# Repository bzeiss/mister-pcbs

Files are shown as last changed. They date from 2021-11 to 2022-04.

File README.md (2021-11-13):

# mister-pcbs

This site contains some stuff I have built for the excellent Mister project. You can more about the Mister project here: https://github.com/MiSTer-devel/Main_MiSTer/wiki

I tinker with electronics, release stuff when I feel like it and I make it public when it's maybe not perfect. I'm not an electronics expert, so I may not always know what I'm doing. I learn the necessary electronics as I use it. Use at your own risk.

Be smart. Don't just trust the stuff I offer for download here. Take a look at the schematic and the PCB design beforehand. 

Feedback is always very welcome :smile: Feel free to ask question in the [discussions](https://github.com/bzeiss/mister-pcbs/discussions).

***

The main content of this site (descriptions, documentations) can be found **[in the Wiki](https://github.com/bzeiss/mister-pcbs/wiki)**.

Entrance (https://github.com/bzeiss/mister-pcbs/wiki)

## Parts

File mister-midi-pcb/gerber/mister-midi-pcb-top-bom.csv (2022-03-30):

Comment | Designator | Footprint | LCSC Part Number
100nF | C1 | Capacitor_SMD:C_0805_2012Metric_Pad1.18x1.45mm_HandSolder | C49678
10uF | C2,C3 | Capacitor_Tantalum_SMD:CP_EIA-3216-18_Kemet-A_Pad1.58x1.35mm_HandSolder | C7171
1N4148 | D1 | Diode_SMD:D_SOD-323_HandSoldering | C2128
Green LED | D2 | LED_SMD:LED_0805_2012Metric_Pad1.15x1.40mm_HandSolder | C2297
Blue LED | D3 | LED_SMD:LED_0805_2012Metric_Pad1.15x1.40mm_HandSolder | C2293
Yellow LED | D4 | LED_SMD:LED_0805_2012Metric_Pad1.15x1.40mm_HandSolder | C2296
Ferrite_Bead | FB1,FB2,FB3,FB4,FB5,FB6 | Capacitor_SMD:C_0805_2012Metric_Pad1.18x1.45mm_HandSolder | C85835
220 | R1 | Resistor_SMD:R_0805_2012Metric_Pad1.20x1.40mm_HandSolder | C17557
470 | R2 | Resistor_SMD:R_0805_2012Metric_Pad1.20x1.40mm_HandSolder | C17710
2k | R3,R8,R9 | Resistor_SMD:R_0805_2012Metric_Pad1.20x1.40mm_HandSolder | C17604
33 | R4,R5 | Resistor_SMD:R_0805_2012Metric_Pad1.20x1.40mm_HandSolder | C17634
10 | R6,R7 | Resistor_SMD:R_0805_2012Metric_Pad1.20x1.40mm_HandSolder | C17415
H11L1 | U1 | Package_DIP:SMDIP-6_W9.53mm_Clearance8mm | C899473
74HC14 | U2 | Package_SO:SO-14_3.9x8.65mm_P1.27mm | C5605
LM1117-3.3 | U3 | Package_TO_SOT_SMD:SOT-223-3_TabPin2 | C126027

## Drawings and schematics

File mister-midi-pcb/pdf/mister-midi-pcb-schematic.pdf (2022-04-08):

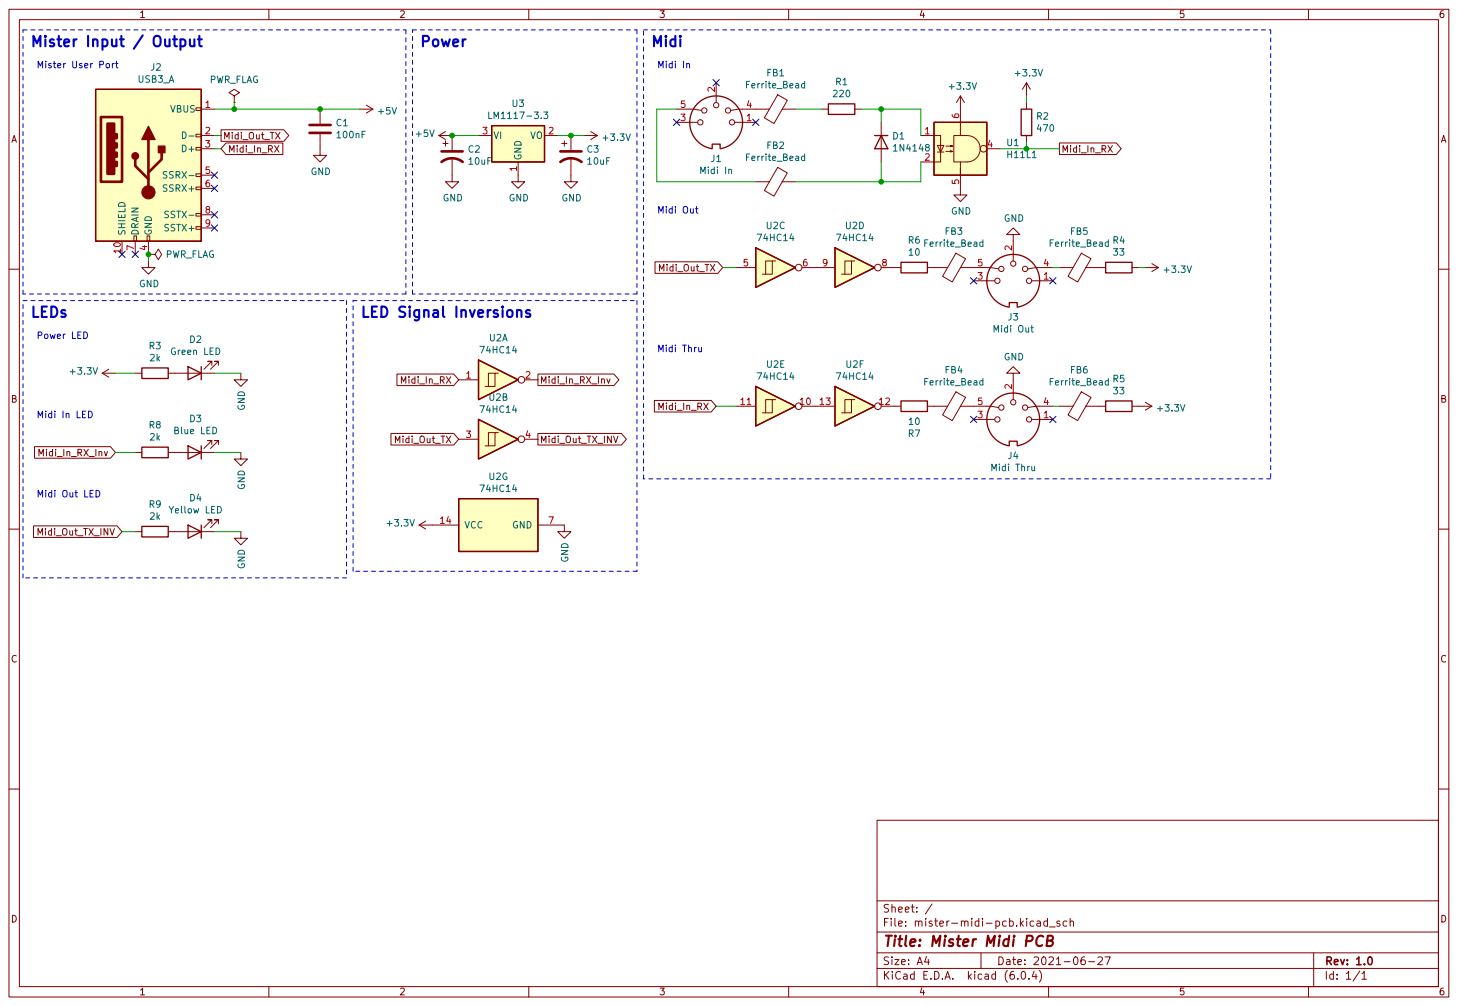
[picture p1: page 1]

Power LED Mister Input / Output

5 6 U1H11L1 Midi_In_RX Midi_Out_TX Midi_In_RX_Inv Midi_Out_TX Midi_In_RX Midi_In_RX Midi_In_RX_Inv Midi_Out_TX Midi_Out_TX_INV Midi_In_RX Midi_Out_TX_INV Midi Thru Midi Out Midi Midi In Midi Out LED Midi In LED Power

File: mister-midi-pcb.kicad_sch Sheet: /
Id: 1/1 Title: Mister Midi PCB

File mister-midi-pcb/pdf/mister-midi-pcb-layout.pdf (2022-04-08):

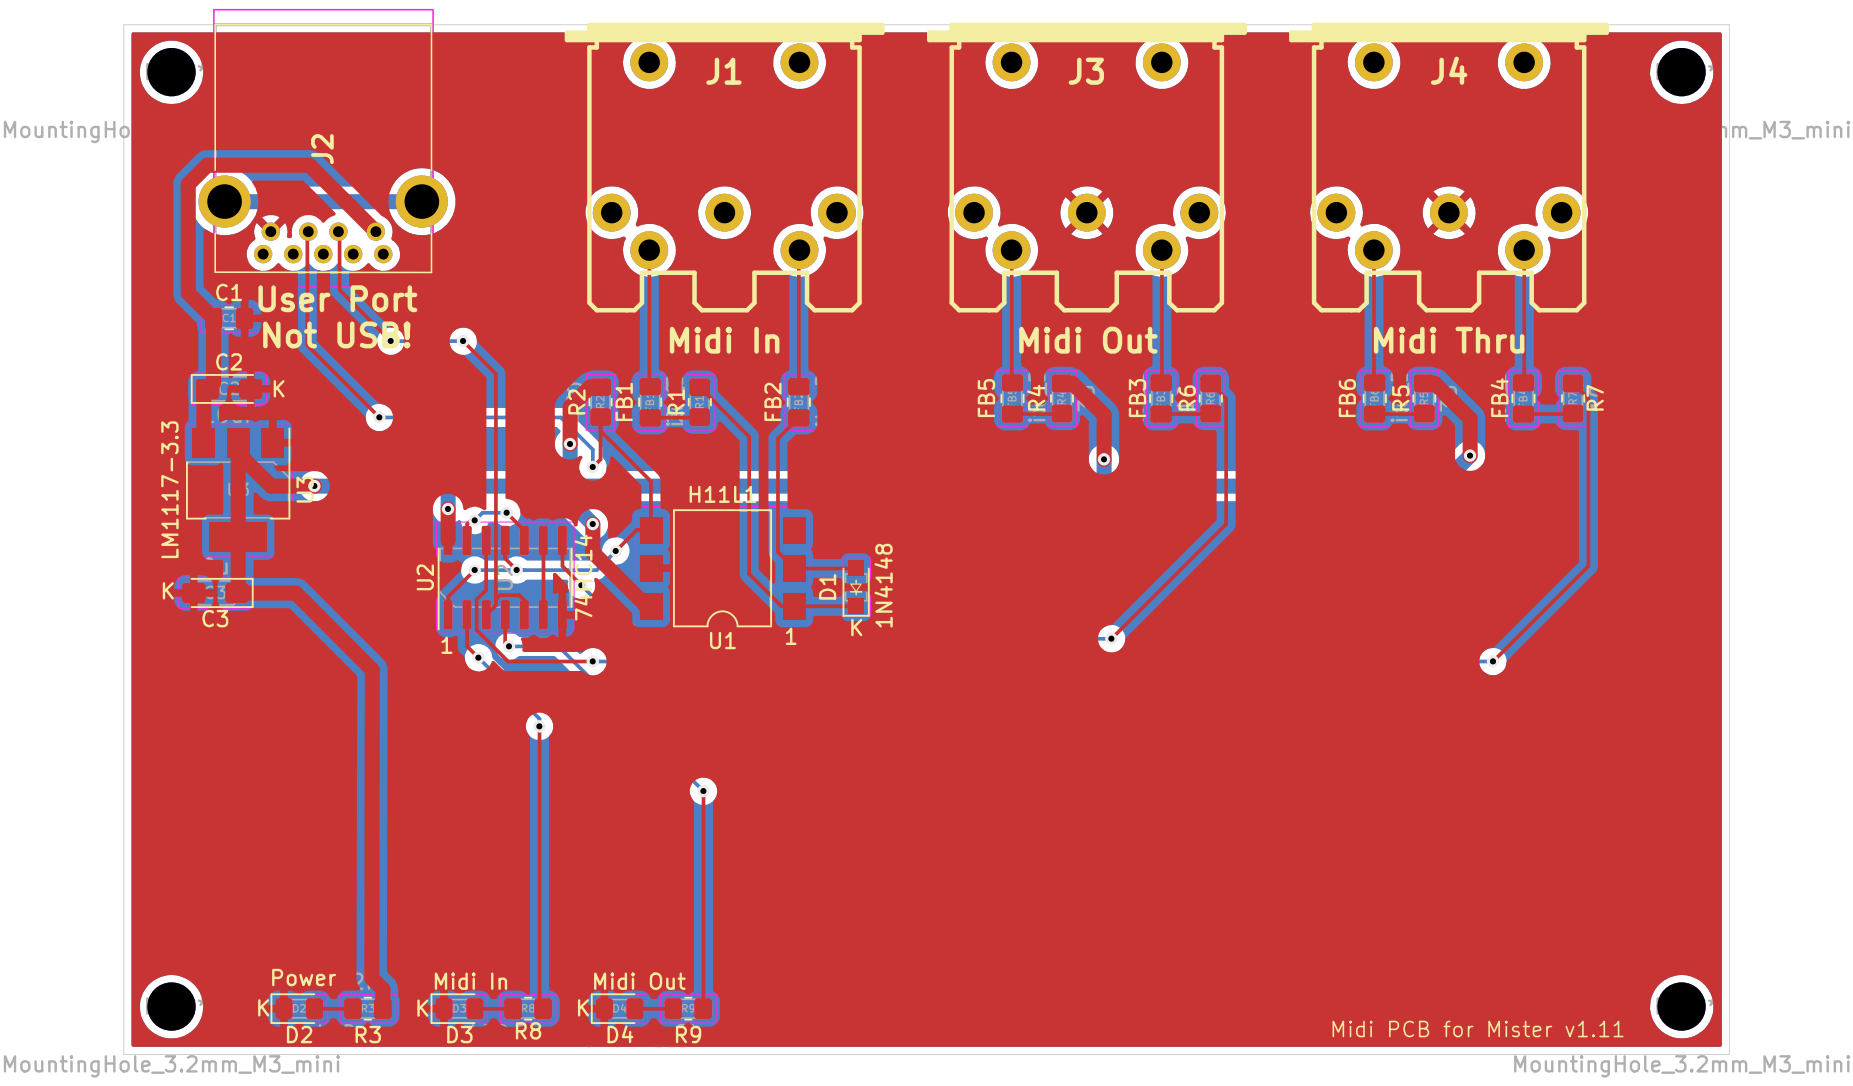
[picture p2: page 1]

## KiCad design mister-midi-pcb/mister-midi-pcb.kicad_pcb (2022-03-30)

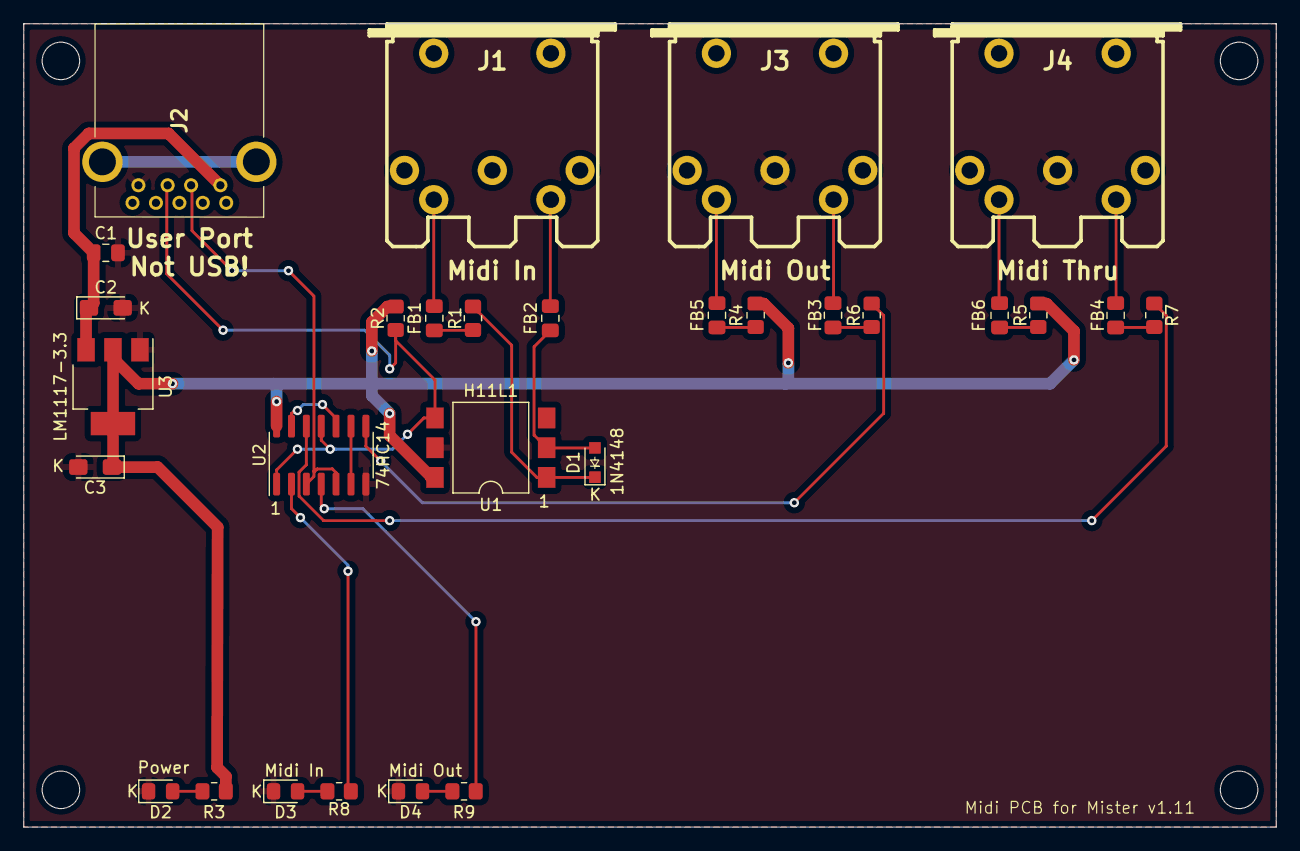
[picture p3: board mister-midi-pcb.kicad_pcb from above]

Board: 2 copper layers, 106.9 x 68.6 mm, 29 parts (0 on the bottom side), 27 nets.

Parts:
C1: 100nF; C_0805_2012Metric_Pad1.18x1.45mm_HandSolder
C2, C3: 10uF; CP_EIA-3216-18_Kemet-A_Pad1.58x1.35mm_HandSolder
D1: 1N4148; D_SOD-323_HandSoldering
D2: Green LED; LED_0805_2012Metric_Pad1.15x1.40mm_HandSolder
D3: Blue LED; LED_0805_2012Metric_Pad1.15x1.40mm_HandSolder
D4: Yellow LED; LED_0805_2012Metric_Pad1.15x1.40mm_HandSolder
FB1, FB2, FB3, FB4, FB5, FB6: Ferrite_Bead; C_0805_2012Metric_Pad1.18x1.45mm_HandSolder
J1: Midi In; din-5
J2: USB3_A; GSB3111113HR
J3: Midi Out; din-5
J4: Midi Thru; din-5
R1: 220; R_0805_2012Metric_Pad1.20x1.40mm_HandSolder
R2: 470; R_0805_2012Metric_Pad1.20x1.40mm_HandSolder
R3, R8, R9: 2k; R_0805_2012Metric_Pad1.20x1.40mm_HandSolder
R4, R5: 33; R_0805_2012Metric_Pad1.20x1.40mm_HandSolder
R6, R7: 10; R_0805_2012Metric_Pad1.20x1.40mm_HandSolder
U1: H11L1; SMDIP-6_W9.53mm_Clearance8mm
U2: 74HC14; SO-14_3.9x8.65mm_P1.27mm
U3: LM1117-3.3; SOT-223-3_TabPin2

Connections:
+3V3: C3.1, R2.1, R3.2, R4.2, R5.2, U1.6, U2.14 (VCC), U3.2 (VO)
+5V: C1.1, C2.1, J2.1 (VBUS), U3.3 (VI)
GND: C1.2, C2.2, C3.2, D2.1 (K), D3.1 (K), D4.1 (K), J2.4 (GND), J3.2, J4.2, U1.5, U2.7 (GND), U3.1 (GND)
Midi_In_RX: J2.3 (D+), R2.2, U1.4, U2.1, U2.11
Midi_In_RX_Inv: R8.2, U2.2
Midi_Out_TX: J2.2 (D-), U2.3, U2.5
Midi_Out_TX_INV: R9.2, U2.4
unnamed: D1.1 (K), R1.1, U1.1
unnamed: D1.2 (A), FB2.1, U1.2
unnamed: D2.2 (A), R3.1
unnamed: D3.2 (A), R8.1
unnamed: D4.2 (A), R9.1
unnamed: FB1.1, R1.2
unnamed: FB1.2, J1.4
unnamed: FB2.2, J1.5
unnamed: FB3.1, J3.5
unnamed: FB3.2, R6.2
unnamed: FB4.1, J4.5
unnamed: FB4.2, R7.1
unnamed: FB5.1, R4.1
unnamed: FB5.2, J3.4
unnamed: FB6.1, R5.1
unnamed: FB6.2, J4.4
unnamed: R6.1, U2.8
unnamed: R7.2, U2.12
unnamed: U2.6, U2.9
unnamed: U2.10, U2.13

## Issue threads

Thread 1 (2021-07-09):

Fix incorrect USB3 User Port footprint

bzeiss, 2021-07-09:

Closed 2022-04-08.

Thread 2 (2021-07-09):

Fix Holes M2.5 -> M3

bzeiss, 2021-07-09:
The holes are too small for the Mister stack..

Closed 2021-07-09.

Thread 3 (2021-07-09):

Check C2/C3 tantal capacitor footprints

bzeiss, 2021-07-09:
The footprint is too small for the bought ones. Buy either smaller capacitors or correct the footprint size.

Closed 2022-04-08.

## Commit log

2021-06-22 reworked pcb with 3.3v
    [mister-midi-pcb.kicad_pcb, mister-midi-pcb.sch]
2021-06-22 small fix.
    [mister-midi-pcb.kicad_pcb]
2021-06-22 gerber files
    [mister-midi-pcb-B_Cu.gbr, mister-midi-pcb-B_Mask.gbr, mister-midi-pcb-B_Paste.gbr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]
2021-06-24 out and thru go through buffer now.
    [mister-midi-pcb.kicad_pcb, mister-midi-pcb.sch]
2021-06-24 updated gerber.
    [mister-midi-pcb-B_Cu.gbr, mister-midi-pcb-B_Mask.gbr, mister-midi-pcb-B_Paste.gbr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]
2021-06-26 small trace improvements.
    [mister-midi-pcb-B_Cu.gbr, mister-midi-pcb-B_Mask.gbr, mister-midi-pcb-B_Paste.gbr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]
2021-06-26 added capacitors for ldo
    [mister-midi-pcb-B_Cu.gbr, mister-midi-pcb-B_Mask.gbr, mister-midi-pcb-B_Paste.gbr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]
2021-06-27 updated gerbers, holes were missing.
    [mister-midi-pcb-B_Cu.gbr, mister-midi-pcb-B_Mask.gbr, mister-midi-pcb-B_Paste.gbr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]
2021-07-09 Fix #2,#3
    [mister-midi-pcb.kicad_pcb]
2021-07-12 v1.1 of the midi pcb. fixed a couple of problems from the first prototype board.
    [mister-midi-pcb-B_Cu.gbr, mister-midi-pcb-B_Mask.gbr, mister-midi-pcb-B_Paste.gbr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]
2021-09-06 added bom
2022-03-30 kicad 6 migration, jlcpcb assembly files.
    [mister-midi-pcb-B_Cu.gbr, mister-midi-pcb-B_Mask.gbr, mister-midi-pcb-B_SilkS.gbr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]
